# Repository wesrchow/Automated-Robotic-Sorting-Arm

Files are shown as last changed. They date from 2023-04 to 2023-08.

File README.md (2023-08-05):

# Automated-Robotic-Sorting-Arm
_(Developed for my CPEN design studio class with a team of 4.)_

An automated robotic sorting arm that was powered by Python and an NVIDIA Jetson Nano. The robotic arm used computer vision machine learning to classify and sort electronic components on a table.

We leveraged the YOLOv5 machine learning model and created our own dataset using Roboflow. Using this object detection, we implemented reverse kinematics to control the robot arm. The arm was built using custom-designed 3D-printed parts, an electromagnet, servo motors and a battery power system.

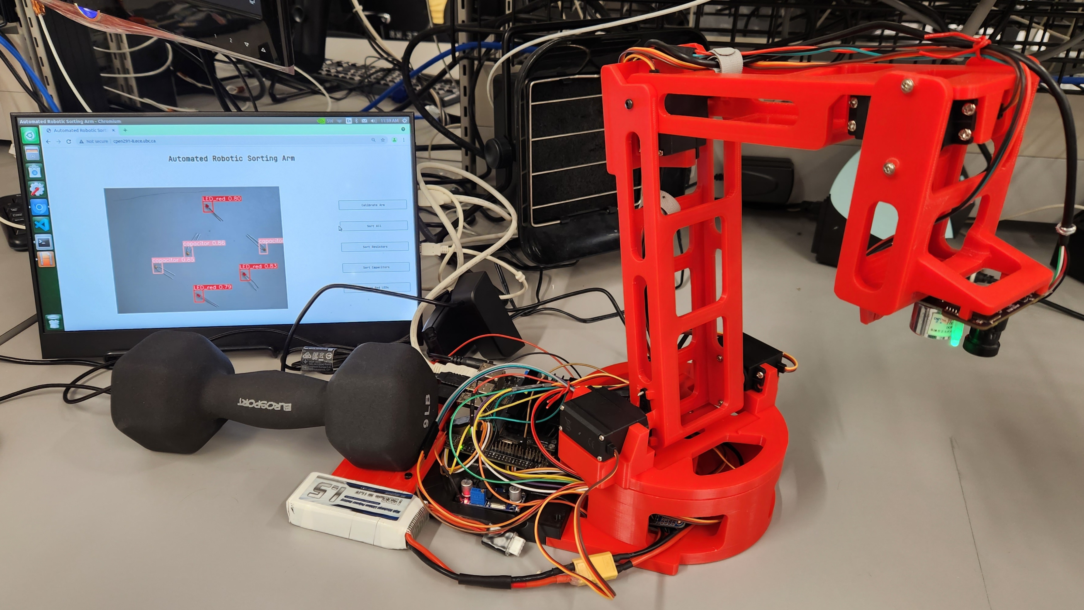
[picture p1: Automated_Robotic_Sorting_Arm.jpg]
Automated Robotic Sorting Arm


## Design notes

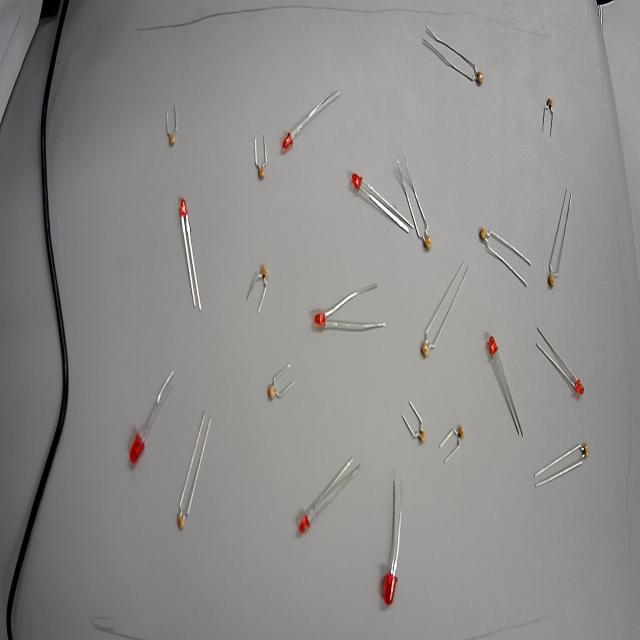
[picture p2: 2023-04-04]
ML_dataset/valid/images/WIN_20230404_09_01_38_Pro_jpg.rf.dd8d5d1574b5a25e2542007a8d4bc09e.jpg

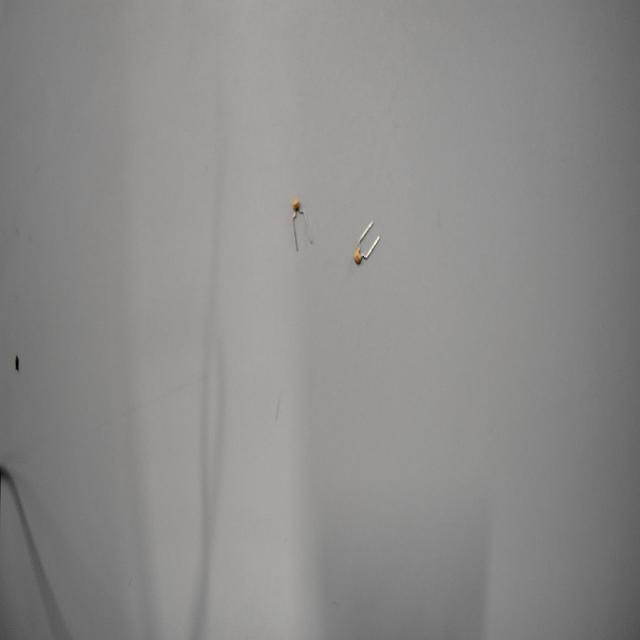
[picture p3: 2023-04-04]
ML_dataset/train/images/WIN_20230320_16_13_17_Pro_jpg.rf.a34ccd946f8d2aaf98a8b6f5cf742267.jpg

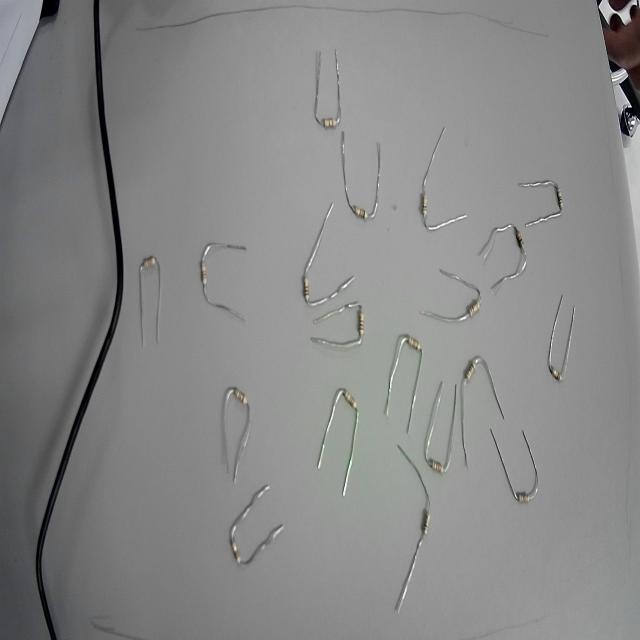
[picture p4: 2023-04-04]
ML_dataset/train/images/WIN_20230404_09_06_13_Pro_jpg.rf.226fbacb9f51d70a6f849d0b956d9061.jpg

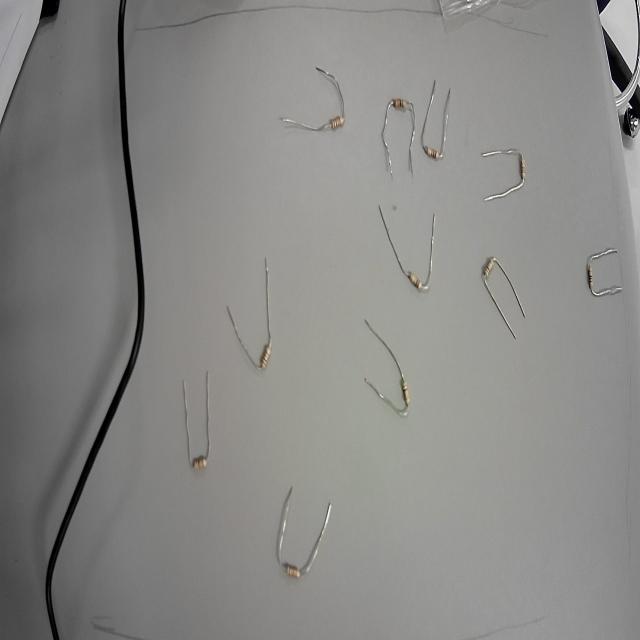
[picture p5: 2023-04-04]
ML_dataset/train/images/WIN_20230404_09_04_37_Pro_jpg.rf.65ceb4eeaddcc33bc4119839481e0961.jpg

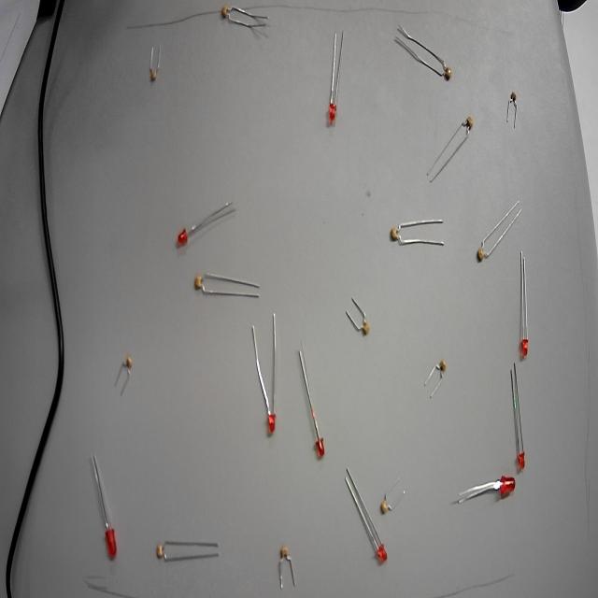
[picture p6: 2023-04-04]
ML_dataset/train/images/WIN_20230404_09_01_17_Pro_jpg.rf.1ae11c0410f9dd4ac13d16b48e1fc742.jpg

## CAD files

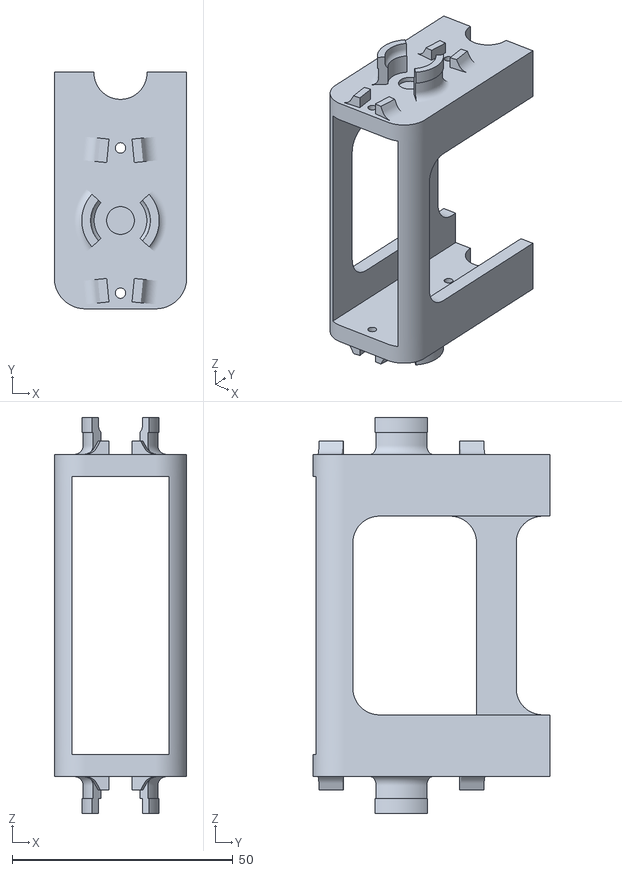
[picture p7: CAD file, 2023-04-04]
3D Design/STL Files/Arm Lower Test 1.stl
30.0 x 53.6 x 89.7

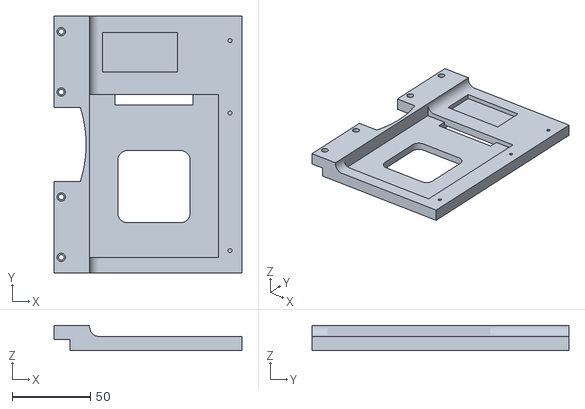
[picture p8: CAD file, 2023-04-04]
3D Design/STL Files/Base Extension 1.stl
119.6 x 163.9 x 16.0

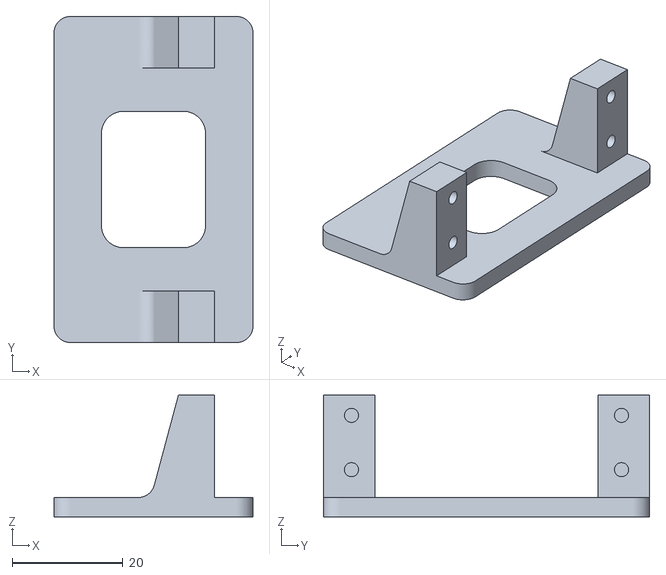
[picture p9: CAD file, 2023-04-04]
3D Design/STL Files/MG996R Attachment Test.stl
36.0 x 59.0 x 22.0

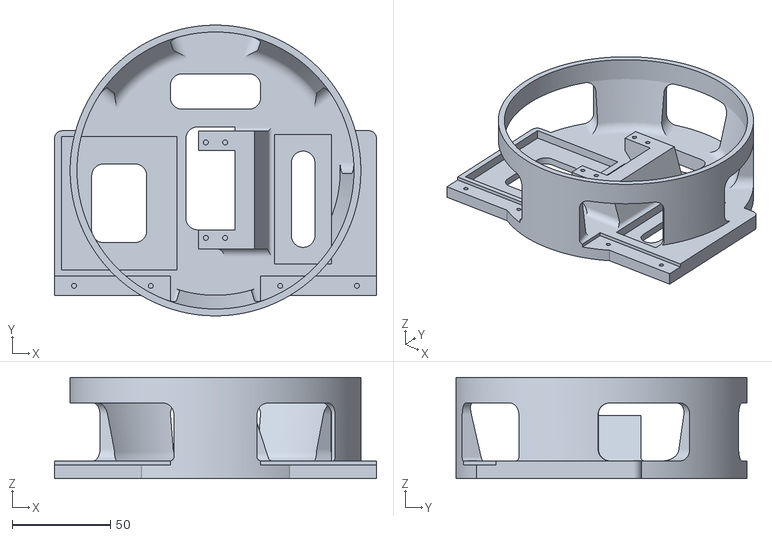
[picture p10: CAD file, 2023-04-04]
3D Design/STL Files/Swivel Base.stl
163.9 x 148.0 x 51.5

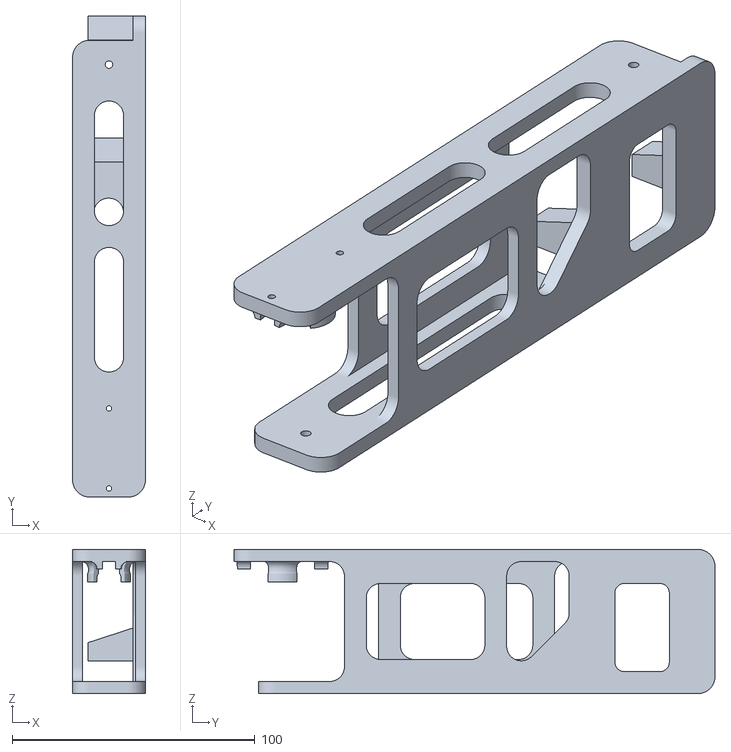
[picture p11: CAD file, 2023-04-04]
3D Design/STL Files/Arm Middle.stl
30.0 x 198.0 x 59.3

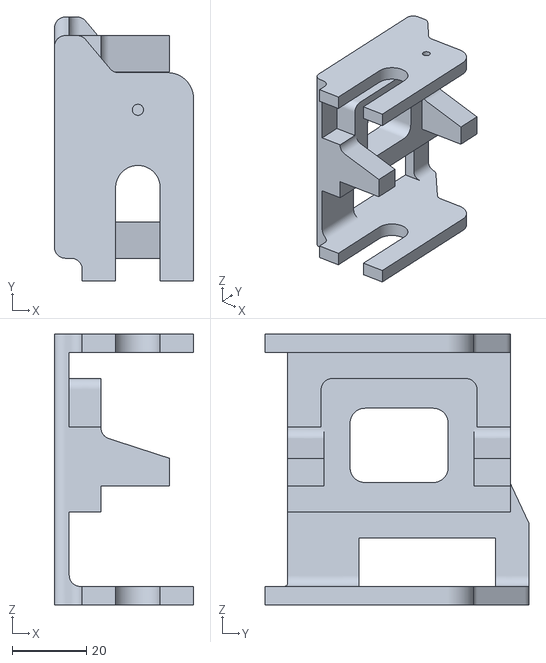
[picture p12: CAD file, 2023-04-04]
3D Design/STL Files/Arm Lower Test 2.stl
37.5 x 71.1 x 73.0

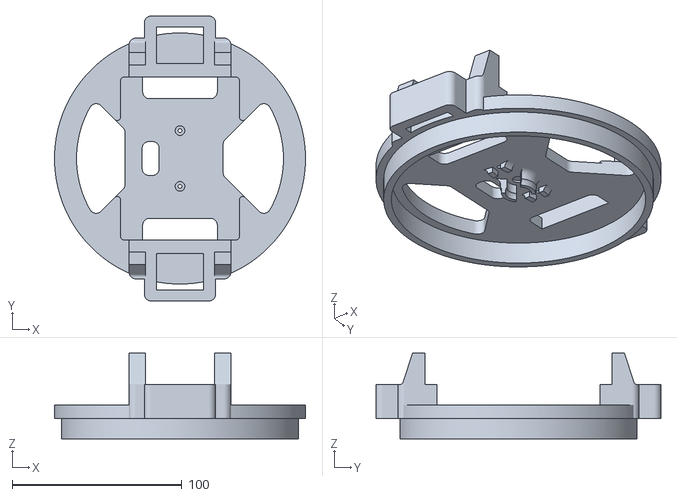
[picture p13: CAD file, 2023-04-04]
3D Design/STL Files/Swivel Top.stl
148.0 x 168.0 x 50.5

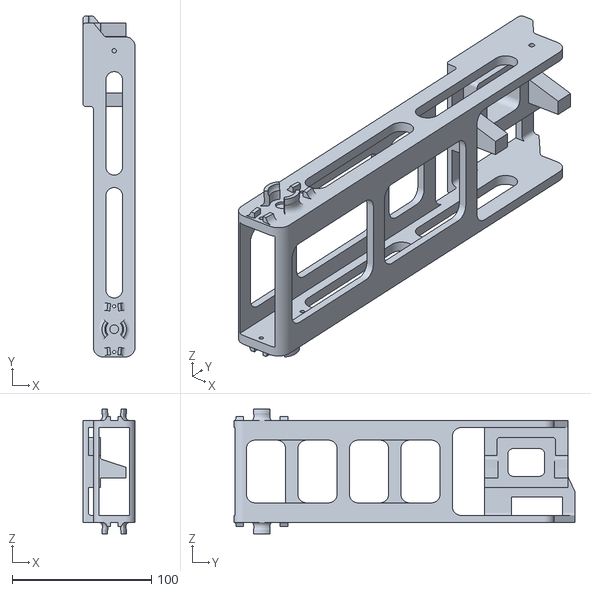
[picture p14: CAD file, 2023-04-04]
3D Design/STL Files/Arm Lower.stl
37.5 x 245.0 x 89.7

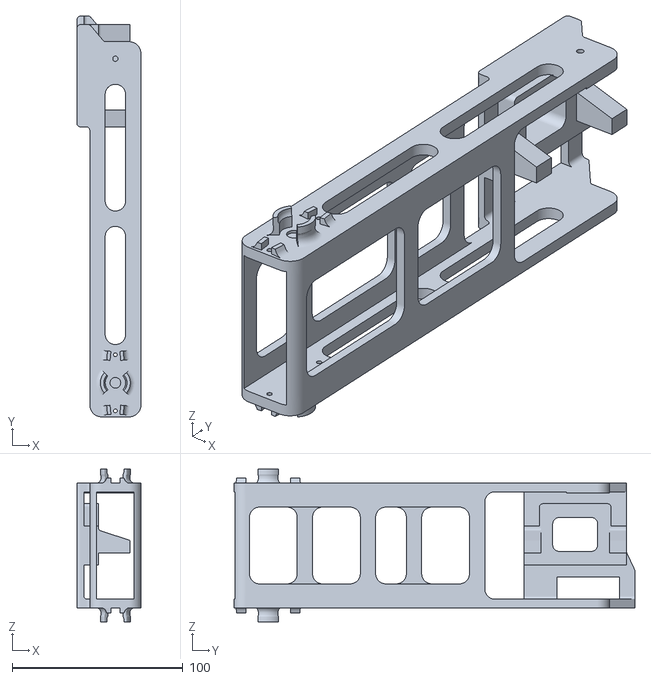
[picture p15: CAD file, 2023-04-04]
3D Design/STL Files/Arm Lower Shortened.stl
37.5 x 235.0 x 89.7

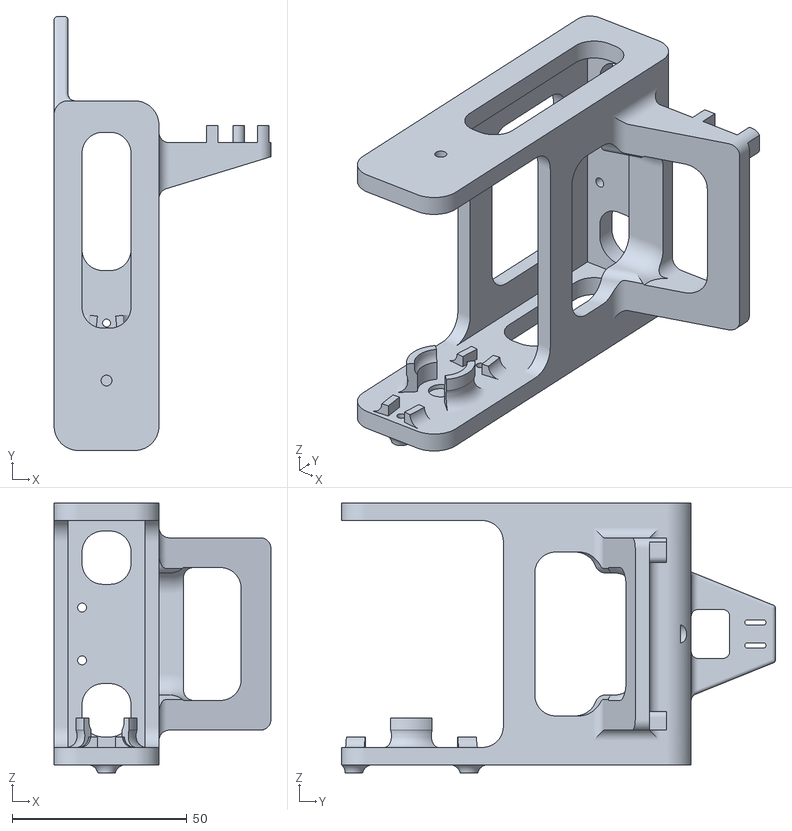
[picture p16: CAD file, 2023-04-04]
3D Design/STL Files/Arm Upper.stl
62.0 x 124.1 x 77.1

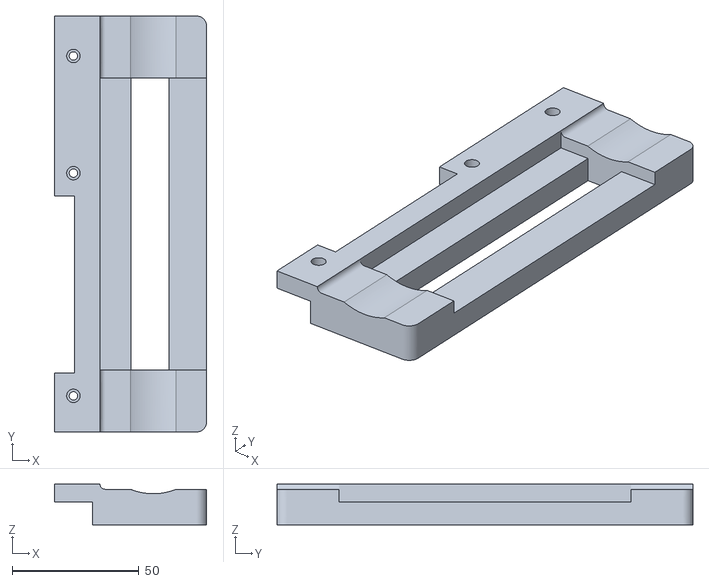
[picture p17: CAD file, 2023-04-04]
3D Design/STL Files/Base Extension 2.stl
60.0 x 163.9 x 16.0

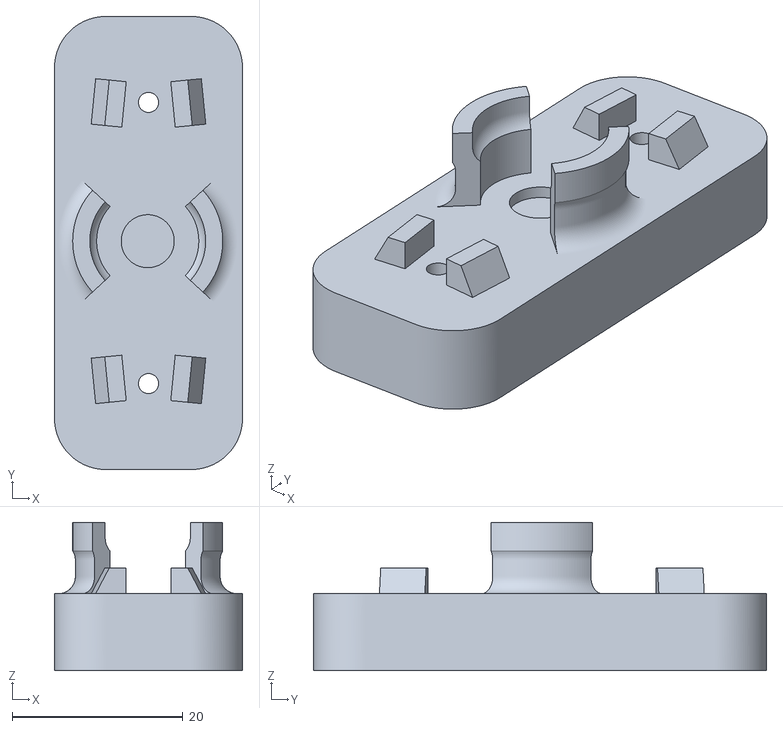
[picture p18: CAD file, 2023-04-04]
3D Design/STL Files/MG996R Arm Test.stl
22.0 x 53.0 x 17.4

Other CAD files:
3D Design/Arm Full Assembly.iam
3D Design/Arm Lower Bottom.ipt
3D Design/Arm Lower Shortened.iam
3D Design/Arm Lower Top.ipt
3D Design/Arm Lower.ipt
3D Design/Arm Middle.ipt
3D Design/Arm Upper.ipt
3D Design/Base Extension 1.ipt
3D Design/Base Extension 2.ipt
3D Design/Drafting/Arm Lower Test 1.ipt
3D Design/Drafting/Arm Lower Test 2.ipt
3D Design/Drafting/Base Electronics Measurements.ipt
3D Design/Drafting/Camera Measurements.ipt
3D Design/Drafting/Electromagnet Measurements.ipt
3D Design/Drafting/MG996R Arm Test.ipt
3D Design/Drafting/MG996R Attachment Test.ipt
3D Design/Drafting/Swivel Top Drafting.ipt
3D Design/Robot Arm Concept.blend
3D Design/Swivel Base.ipt
3D Design/Swivel Top.ipt

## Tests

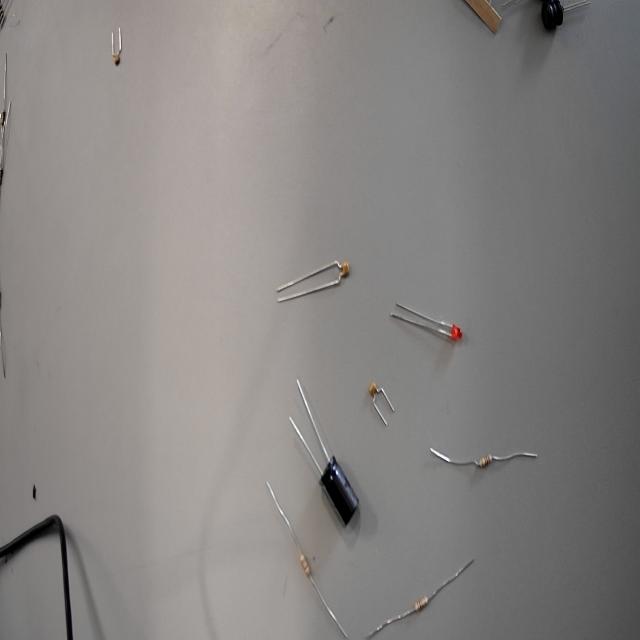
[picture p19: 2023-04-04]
ML_dataset/test/images/WIN_20230320_16_22_52_Pro_jpg.rf.7f86a074a1b466607a6baccf5cfe7ae4.jpg

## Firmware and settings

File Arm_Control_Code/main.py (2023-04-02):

import Arm
import time

if __name__ == "__main__":

    prob_min = 0.50
    base = Arm.Base(0)
    shoulder = Arm.Shoulder(115)
    elbow = Arm.Elbow(70)
    wrist = Arm.Wrist(45)
    x_sent = 2
    y_sent = 2
    x_prev = -1
    y_prev = -1
    prob_sent = 0.9
    while True:
        if x_sent != x_prev and y_sent != y_prev and prob_sent > prob_min:
            Arm.update_state(base, shoulder, elbow, wrist)
            x_prev = x_sent
            y_prev = y_sent

        if base.state == 1:
            base.update_dist(x_sent, y_sent)
            Arm.update_distances(base, shoulder, elbow, wrist)
            base.point_arm(x_sent, y_sent)
            Arm.update_state(base, shoulder, elbow, wrist)
            time.sleep(2)

        if base.state == 2:
            elbow.finAngle = Arm.cosine_law_angle(elbow.fore_arm_length, elbow.humerus_length, elbow.third_side)
            wrist.finAngle = Arm.cosine_law_angle(wrist.fore_arm_length, wrist.third_side,
                                                  wrist.humerus_length) + 90 + wrist.base_angle_offset
            shoulder.finAngle = Arm.cosine_law_angle(shoulder.humerus_length, shoulder.third_side,
                                                     shoulder.fore_arm_length) - shoulder.base_angle_offset
            # shoulder.interAngle, wrist.interAngle = Arm.cosine_law_side(elbow.finAngle,
            #                                                             wrist.wrist_length, shoulder.humerus_length)
            shoulder.interAngle = shoulder.finAngle + 25
            wrist.interAngle = shoulder.finAngle - 25
            elbow.set_angle_conv(elbow.finAngle)
            wrist.set_angle_conv(wrist.interAngle)
            shoulder.set_angle_conv(shoulder.interAngle)
            Arm.update_state(base, shoulder, elbow, wrist)
            #### write the magnet to high ####
            time.sleep(2)

        if base.state == 3:
            Arm.slow_move_synchro(wrist, shoulder, wrist.finAngle, shoulder.finAngle, 10)
            Arm.update_state(base, shoulder, elbow, wrist)
            time.sleep(2)

        if base.state == 4:
            elbow.set_angle_conv(70)
            wrist.set_angle_conv(120)
            shoulder.set_angle_conv(0)
            Arm.update_state(base, shoulder, elbow, wrist)
            time.sleep(2)

        if base.state == 5:
            base.base_servo = 0
            time.sleep(3)
            #### write the magnet to low ####
            Arm.update_state(base, shoulder, elbow, wrist)
            time.sleep(3)

        #x_sent = val from website
        #y_sent = val from website
        #prob_set = val from website

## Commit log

2023-03-14 create concept blender model, start swivel top draft, add gitignore
    [Robot Arm Concept.blend, Swivel Top Drafting.ipt]
2023-03-16 progress on test models
    [MG996R Arm Test.ipt, Swivel Top Drafting.ipt]
2023-03-17 complete test models
    [MG996R Arm Test.ipt, MG996R Attachment Test.ipt]
2023-03-18 revised test models
    [MG996R Arm Test.ipt, MG996R Attachment Test.ipt]
2023-03-21 update arm test
    [MG996R Arm Test.ipt]
2023-03-21 fix arm test
    [MG996R Arm Test.ipt]
2023-03-21 entirely fix arm test
    [MG996R Arm Test.ipt]
2023-03-21 axle alignment attachment test, arm bottom right progress
    [Arm Bottom Right.ipt, MG996R Attachment Test.ipt]
2023-03-21 attachment test add reference lines, progress arm bottom right
    [Arm Bottom Right.ipt, MG996R Attachment Test.ipt]
2023-03-23 add electromagnet measurements
    [Electromagnet Measurements.ipt]
2023-03-24 create arm bottom left, edit bottom right, add base draft
    [Arm Bottom Left.ipt, Arm Bottom Right.ipt, Base Electronics Measurements.ipt]
2023-03-24 rename to arm lower, initial complete arm lower, fix servo arm test
    [Arm Bottom Right.ipt, Arm Lower.ipt, MG996R Arm Test.ipt]
2023-03-25 remove arm left, update arm lower, organize designs, create test designs
    update gitignore
    [Arm Bottom Left.ipt, Arm Lower Test 1.ipt, Arm Lower Test 2.ipt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]
2023-03-25 update arm lower
    [Arm Lower.ipt]
2023-03-26 update arm lower, arm middle
    [Arm Lower.ipt, Arm Middle.ipt]
2023-03-26 create shortened arm lower version
    [Arm Lower Bottom.ipt, Arm Lower Shortened.iam, Arm Lower Top.ipt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]
2023-03-27 complete all main arm parts
    [Arm Lower Shortened.iam, Arm Upper.ipt, Base Electronics Measurements.ipt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]
2023-03-28 Added a main function with nothing in it yet and almost done the Arm class with all the functions necessary to go through the whole process
2023-03-28 Initial main. Just for testing and initial calibrating
2023-03-28 rename assembly
    [Arm Full Assembly.iam, Full Assembly.iam]
2023-03-28 invert direction of electromagnet, create camera measurements
    [Arm Full Assembly.iam, Arm Upper.ipt, Camera Measurements.ipt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]
2023-03-30 servo testing
2023-04-01 revise arm upper with camera attachment and fixes
    [Arm Upper.ipt, Camera Measurements.ipt]
2023-04-01 lots of progress on swivel top
    [Swivel Top.ipt]
2023-04-01 initial complete swivel top
    [Swivel Top.ipt]
2023-04-01 update swivel top
    [Swivel Top.ipt]
2023-04-02 All that's left should be calibrating
2023-04-02 All that's left should be calibrating and other features such as electromagnet and potentiometer
2023-04-02 arm control
2023-04-02 adding calibrate
2023-04-02 arm 2
2023-04-02 initial complete swivel base
    [Arm Full Assembly.iam, Swivel Base.ipt, Swivel Top.ipt]
2023-04-02 update swivel base
    [Arm Full Assembly.iam, Swivel Base.ipt]
2023-04-02 initial complete base extension 1
    [Base Extension 1.ipt]
2023-04-02 initial complete base extension 2, small updates to other models
    [Arm Full Assembly.iam, Base Extension 1.ipt, Base Extension 2.ipt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]
2023-04-02 update base extension 2
    [Arm Full Assembly.iam, Base Extension 2.ipt]
2023-04-03 All that's left should be calibrating and other features such as electromagnet and potentiometer Attempting to fix slow move :((
2023-04-03 All that's left should be calibrating and other features such as electromagnet and potentiometer Move slow fixed!! Trying to test main turned sort function.
    [mainsafe.py]
2023-04-04 add stl files
    [Arm Lower Shortened.stl, Arm Lower Test 1.stl, Arm Lower Test 2.stl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]
2023-04-04 fritzing file
    [Robotic Arm Electronics.fzz]
2023-04-04 update circuit
    [Robotic Arm Electronics.fzz]
